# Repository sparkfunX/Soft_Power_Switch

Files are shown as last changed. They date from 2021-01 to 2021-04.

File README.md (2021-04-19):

SparkX Soft Power Switch
===================================================

SparkX Soft Power Switch (SPX-17870) (https://www.sparkfun.com/products/17870)

[*SparkX Soft Power Switch (SPX-17870)*](https://www.sparkfun.com/products/17870)

SparkX Soft Power Switch (SPX-17870) (https://www.sparkfun.com/products/17870)

The Soft Power Switch is a passive, hard on/off switch with software feedback and control. In other words, it's like the on/off switch on a laptop. A simple press will turn the system on. Another press can (with MCU intervention) turn off the system. And if things go really wrong, pressing and holding the button will force a power-down. If you're building something with an enclosed battery and need a good power button, this is the board you need.

The Sense/Control pin can act as an output to a microcontroller indicating the state of the power button (high = not pressed, low = user in pressing power button). This can be used as an input to your firmware to begin to shut down before power is lost. Alternatively, the Sense/Control pin can be driven low by the system forcing power off via software. Additionally, the Fast Off pin can be used to immediately power down a system.

The most common use case is something like this:

* Microcontroller begins running code and checks to see if power button is still being pressed for X milliseconds.
* If not, it's just a tap, go back to sleep.
* If yes, power up and run normal program.

Later...

* User presses power button in normal program
* If power button is pressed for <X milliseconds, it's just a tap, ignore.
* If power button is pressed for >X milliseconds, it's time to power down.

The wake-up and power-down times can be tweaked for your own user experience but we found 500ms for power up and 2s for power down work really well.

If needed, pads are provided for a larger, external button. A measurement jumper is available to measure passive and active current so you can verify the quiescent current of your system.

The Soft Power Switch supports battery charging. If the target device has onboard LiPo charging, current can be passed back through the cut-off circuit and charge the battery.

The Soft Power Switch works up to 12V. There is a 3.3V clamping diode to prevent over-voltage exposure.

The current design is good but has a few problems. The 22uF cap we used requires an override time of 13 seconds. Under normal operation, the system will power down as quickly as you define in the code (1-2s) so users will rarely experience this. But if the system locks up, 13s is a long time to wait. We've also seen a few edge cases (low load or no load) where the override cut-off occurs only after the button is held for >13s and then released. This is caused by shorting between the finger on the button and the near by capacitor. Using an external button allows the unit to power down correctly every time.

We'll continue to refine the design but it's really handy as it is so we decided to release it!

Pros:

* Very low <50nA quiescent current
* Hard override power down in case your microcontroller loses its mind
* Sense/Control pin can be connected to a microcontroller 

Cons:

* Limited to 4A
* No AC loads

Repository Contents
-------------------
* **/Firmware** - Example sketches demonstrating how to read and control the switch
* **/Hardware** - Eagle design files (.brd, .sch)
* **LICENSE.md** - license information

Product Versions
----------------
* [SPX-17870](https://www.sparkfun.com/products/17870) - Original SparkX Release.

License Information
-------------------

This product is _**open source**_!

Please review the LICENSE.md file for license information.

If you have any questions or concerns on licensing, please contact technical support on our [SparkFun forums](https://forum.sparkfun.com/viewforum.php?f=123).

Distributed as-is; no warranty is given.

- Your friends at SparkFun.

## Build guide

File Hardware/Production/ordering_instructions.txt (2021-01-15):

panel size, 143x139mm
PCB thickness, 1.6mm
number of layers, 2
soldermask color, Black
silkscreen color, White
oz copper, 1oz
finish, HASL lead free
stencils, none
pcs per panel, 30
min trace width, 0.3048mm / 0.0120in
min drill size, 0.3048mm / 0.0120in

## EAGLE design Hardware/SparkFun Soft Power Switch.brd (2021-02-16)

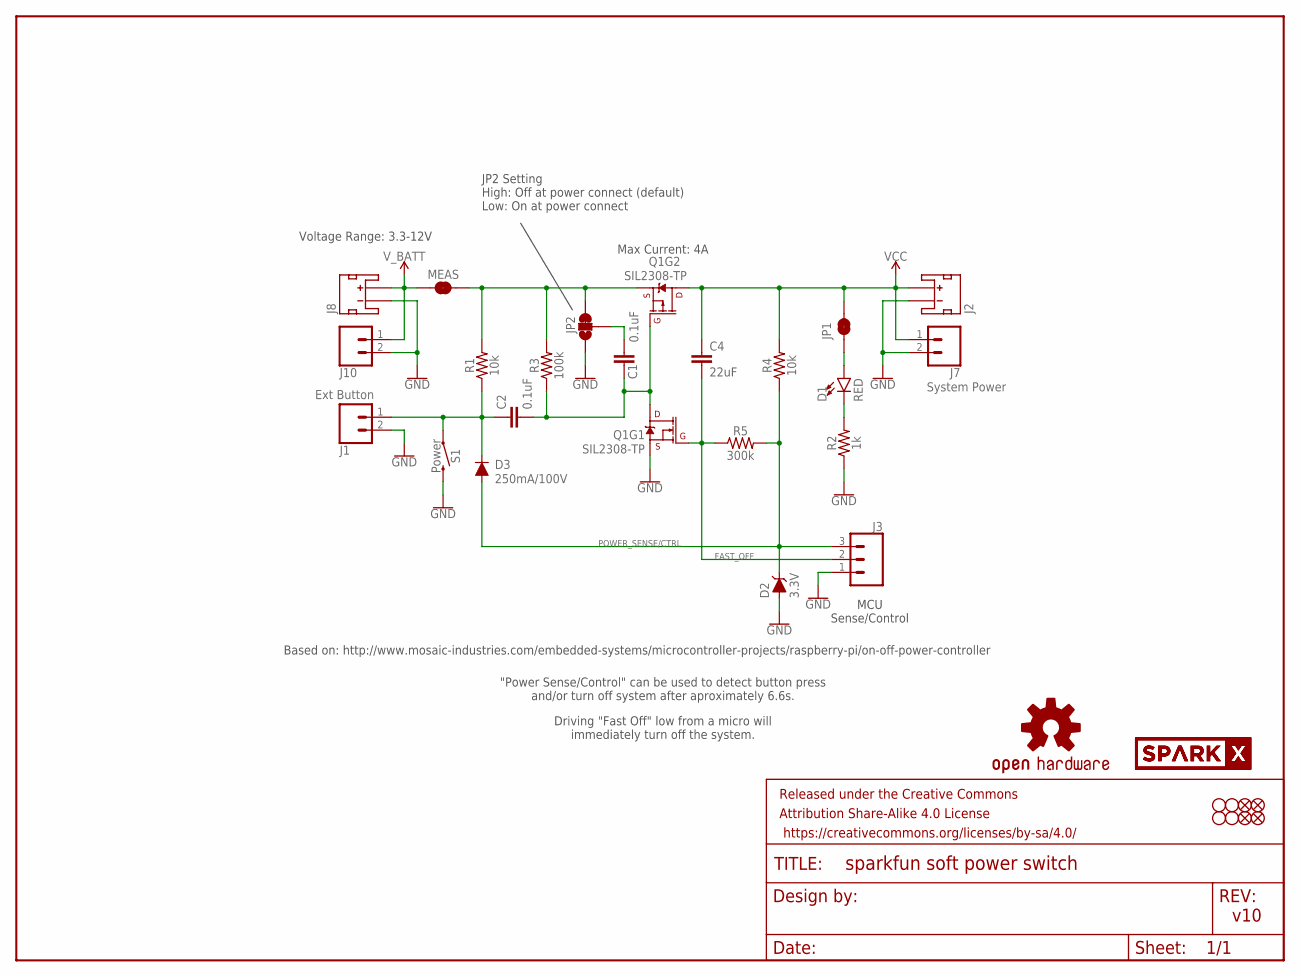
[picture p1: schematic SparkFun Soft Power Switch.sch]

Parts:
C1, C2: 0.1uF; 0603
C4: 22uF; 0805
D1: RED; LED-0603
D2: 3.3V; SOD-323
D3: 250mA/100V; SOD-323
FD1, FD2, FD3, FD4: FIDUCIAL1X2; FIDUCIAL-1X2
FRAME1: FRAME-LETTER; CREATIVE_COMMONS
H1, H2, H3, H4: STAND-OFF
J1: Ext Button; 1X02_NO_SILK
J2, J8: JST_2MM_MALE; JST-2-SMD
J3: CONN_031X03_NO_SILK; 1X03_NO_SILK
J7: System Power; 1X02_NO_SILK
J10: CONN_021X02_NO_SILK; 1X02_NO_SILK
JP1: JUMPER-SMT_2_NC_TRACE_SILK; SMT-JUMPER_2_NC_TRACE_SILK
JP2: JUMPER-SMT_3_1-NC_TRACE_SILK; SMT-JUMPER_3_1-NC_TRACE_SILK
LOGO1: OSHW-LOGOS; OSHW-LOGO-S
MEAS: JUMPER-COMBO_2_NC_TRACE; COMBO-JUMPER_2_NC_TRACE
Q1: SIL2308-TP; SOT26
R1, R4: 10k; 0603
R2: 1k; 0603
R3: 100k; 0603
R5: 300k; 0603
S1: Power; TACTILE_SWITCH_SMD_5.2MM
U$1: SPARKX-LOGO3; SPARKX-SMALL
U$15: SPARKX-LOGO2; SPARKX-TINY

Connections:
FAST_OFF: C4.2, J3.2, Q1.G1 (G), R5.1
GND: D2.A, J1.2, J2.1 (-), J3.1, J7.2, J8.1 (-), J10.2, JP2.1, Q1.S1 (S), R2.1, S1.3 (2)
unnamed: C1.2, JP2.2
unnamed: D1.A, JP1.1
unnamed: D1.C, R2.2
unnamed: C1.1, C2.2, Q1.D1 (D), Q1.G2 (G), R3.1
POWER_BTN: C2.1, D3.C, J1.1, R1.1, S1.1
POWER_SENSE/CTRL: D2.C, D3.A, J3.3, R4.1, R5.2
VCC: C4.1, J2.2 (+), J7.1, JP1.2, Q1.D2 (D), R4.2
V_BATT: J8.2 (+), J10.1, MEAS.1, MEAS.3 (1)
V_IN: JP2.3, MEAS.2, MEAS.4 (2), Q1.S2 (S), R1.2, R3.2

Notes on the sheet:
v10
Voltage Range: 3.3-12V
Based on: http://www.mosaic-industries.com/embedded-systems/microcontroller-projects/raspberry-pi/on-off-power-controller
Max Current: 4A
JP2 Setting High: Off at power connect (default) Low: On at power connect
MCU Sense/Control
"Power Sense/Control" can be used to detect button press and/or turn off system after aproximately 6.6s.
Driving "Fast Off" low from a micro will immediately turn off the system.

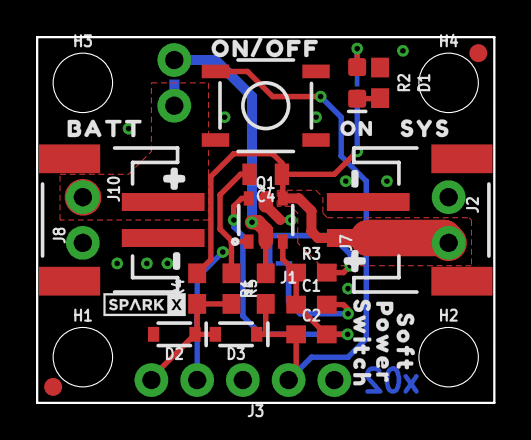
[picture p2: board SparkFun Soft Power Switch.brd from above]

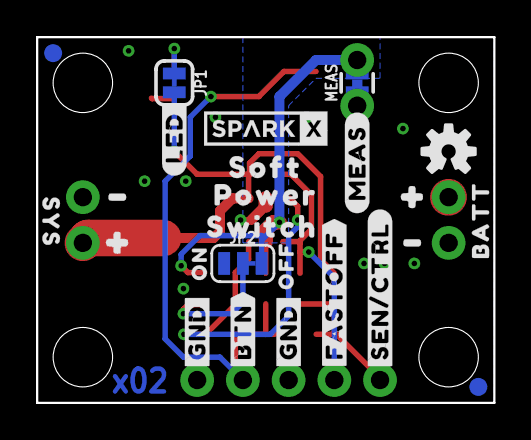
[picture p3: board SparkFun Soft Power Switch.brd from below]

Board: 2 copper layers, 25.4 x 20.3 mm, 63 parts (25 on the bottom side), 11 nets.

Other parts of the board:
U$2: #BTN#2
U$3, U$4: #GND#0
U$5: #SEN#CTRL#1
U$6: ON#OFF0
U$7, U$29: BATT0
U$8, U$31: SYS1
U$9, U$10, U$14, U$22: #0
U$11, U$12, U$20, U$23: #1
U$13: #MEAS#0
U$16: OFF1
U$17: SWITCH2
U$18, U$25: ON0
U$19: #LED#0
U$21: SOFT_0
U$24: POWER_1
U$26: #FASTOFF#0
U$27: SOFT0
U$28: POWER1
U$30: SWITCH_2

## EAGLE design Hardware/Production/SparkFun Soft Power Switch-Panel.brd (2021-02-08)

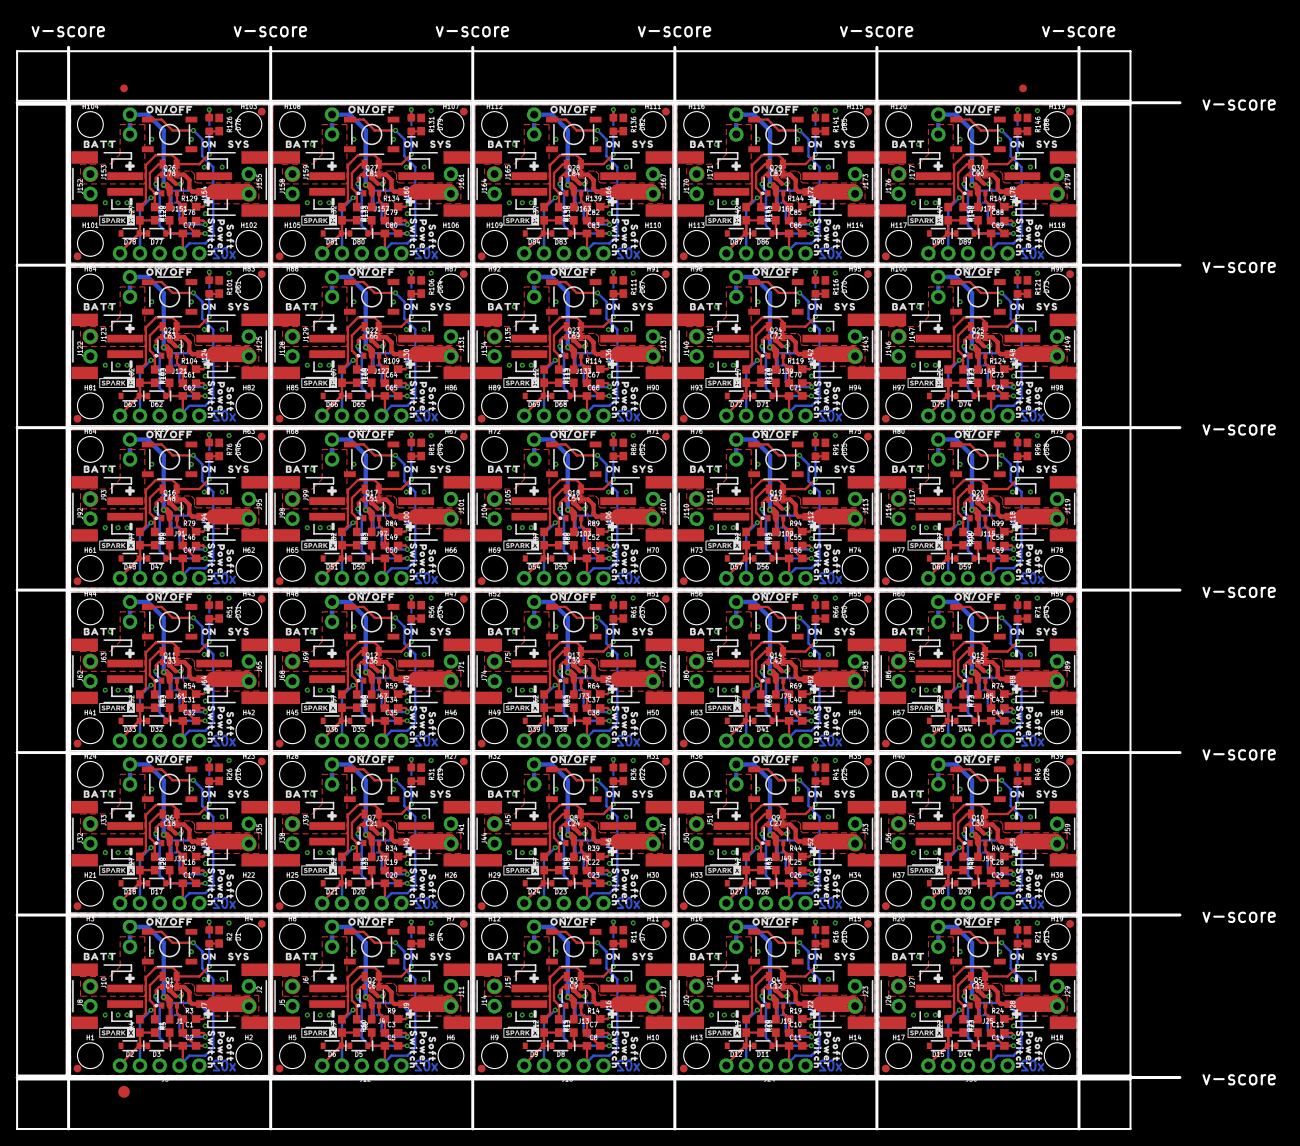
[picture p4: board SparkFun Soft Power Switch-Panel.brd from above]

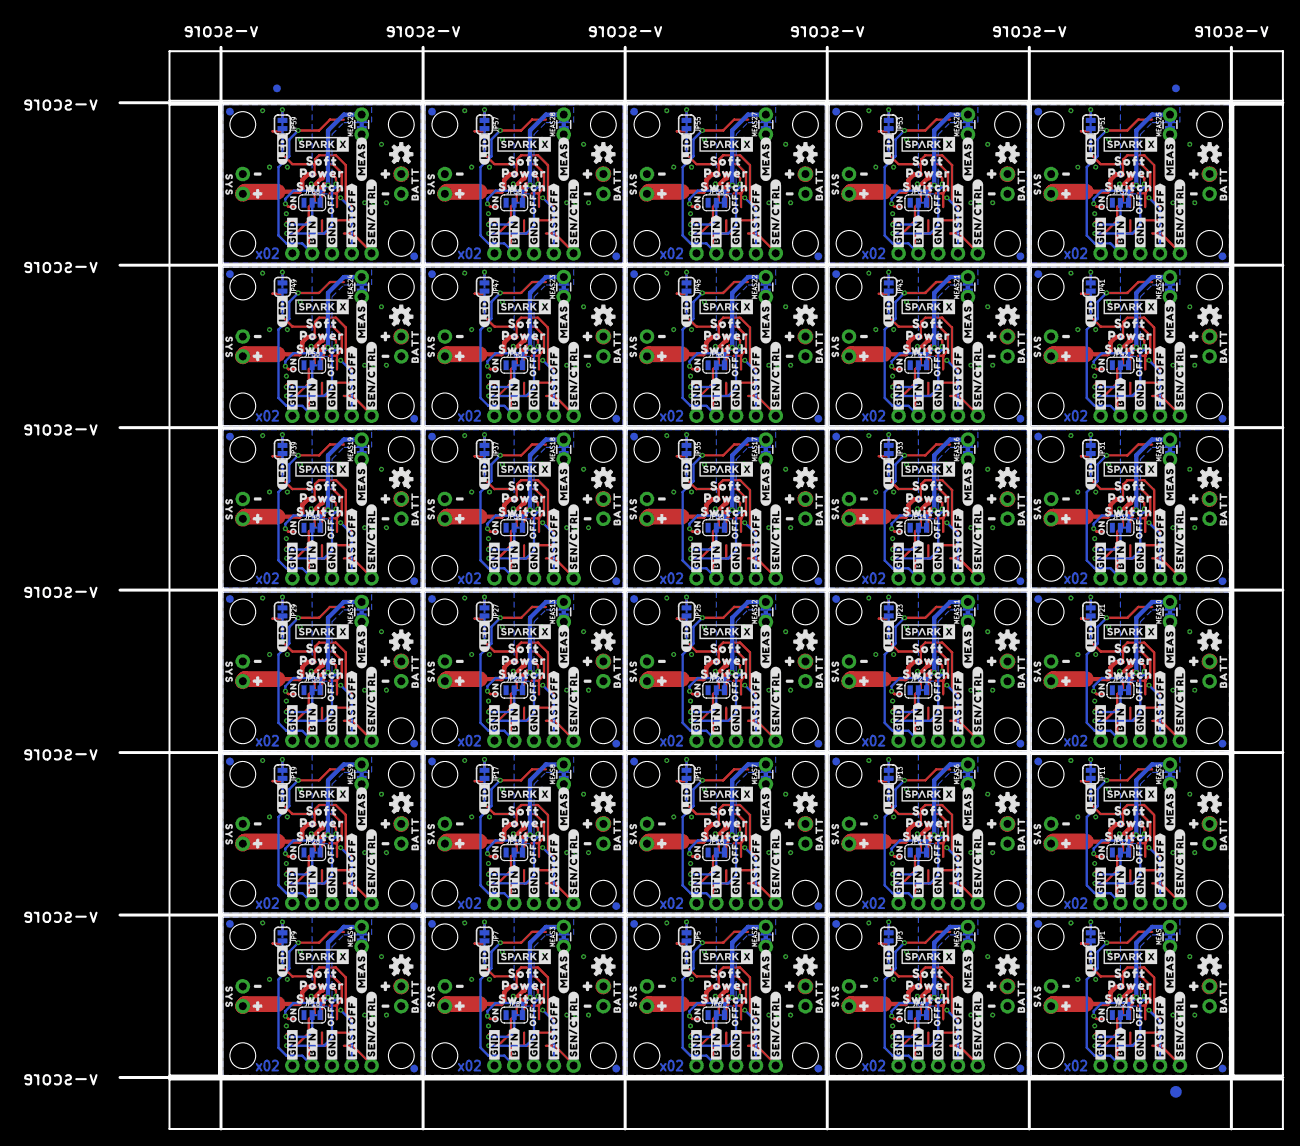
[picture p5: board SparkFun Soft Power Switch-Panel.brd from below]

Board: 2 copper layers, 149.1 x 138.7 mm, 1866 parts (753 on the bottom side), 330 nets.

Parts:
C1, C2, C3, C5, C7, C8, C10, C11, C13, C14, C16, C17, C19, C20, C22, C23, C25, C26, C28, C29, C31, C32, C34, C35, C37, C38, C40, C41, C43, C44, C46, C47, C49, C50, C52, C53, C55, C56, C58, C59, C61, C62, C64, C65, C67, C68, C70, C71, C73, C74, C76, C77, C79, C80, C82, C83, C85, C86, C88, C89: 0.1uF; 0603
C4, C6, C9, C12, C15, C18, C21, C24, C27, C30, C33, C36, C39, C42, C45, C48, C51, C54, C57, C60, C63, C66, C69, C72, C75, C78, C81, C84, C87, C90: 22uF; 0805
D1, D4, D7, D10, D13, D16, D19, D22, D25, D28, D31, D34, D37, D40, D43, D46, D49, D52, D55, D58, D61, D64, D67, D70, D73, D76, D79, D82, D85, D88: Power; LED-0603
D2, D6, D9, D12, D15, D18, D21, D24, D27, D30, D33, D36, D39, D42, D45, D48, D51, D54, D57, D60, D63, D66, D69, D72, D75, D78, D81, D84, D87, D90: 3.3V; SOD-323
D3, D5, D8, D11, D14, D17, D20, D23, D26, D29, D32, D35, D38, D41, D44, D47, D50, D53, D56, D59, D62, D65, D68, D71, D74, D77, D80, D83, D86, D89: 250mA/100V; SOD-323
E$1, E$2, E$3, E$4: FIDUCIAL-1X2
E$5, E$6: FIDUCIAL-1.5X3
FD1, FD2, FD3, FD4, FD5, FD6, FD7, FD8, FD9, FD10, FD11, FD12, FD13, FD14, FD15, FD16, FD17, FD18, FD19, FD20, FD21, FD22, FD23, FD24, FD25, FD26, FD27, FD28, FD29, FD30, FD31, FD32, FD33, FD34, FD35, FD36, FD37, FD38, FD39, FD40, FD41, FD42, FD43, FD44, FD45, FD46, FD47, FD48, FD49, FD50, FD51, FD52, FD53, FD54, FD55, FD56, FD57, FD58, FD59, FD60, FD61, FD62, FD63, FD64, FD65, FD66, FD67, FD68, FD69, FD70, FD71, FD72, FD73, FD74, FD75, FD76, FD77, FD78, FD79, FD80, FD81, FD82, FD83, FD84, FD85, FD86, FD87, FD88, FD89, FD90, FD91, FD92, FD93, FD94, FD95, FD96, FD97, FD98, FD99, FD100, FD101, FD102, FD103, FD104, FD105, FD106, FD107, FD108, FD109, FD110, FD111, FD112, FD113, FD114, FD115, FD116, FD117, FD118, FD119, FD120: FIDUCIAL1X2; FIDUCIAL-1X2
H1, H2, H3, H4, H5, H6, H7, H8, H9, H10, H11, H12, H13, H14, H15, H16, H17, H18, H19, H20, H21, H22, H23, H24, H25, H26, H27, H28, H29, H30, H31, H32, H33, H34, H35, H36, H37, H38, H39, H40, H41, H42, H43, H44, H45, H46, H47, H48, H49, H50, H51, H52, H53, H54, H55, H56, H57, H58, H59, H60, H61, H62, H63, H64, H65, H66, H67, H68, H69, H70, H71, H72, H73, H74, H75, H76, H77, H78, H79, H80, H81, H82, H83, H84, H85, H86, H87, H88, H89, H90, H91, H92, H93, H94, H95, H96, H97, H98, H99, H100, H101, H102, H103, H104, H105, H106, H107, H108, H109, H110, H111, H112, H113, H114, H115, H116, H117, H118, H119, H120: STAND-OFF
J1, J4, J13, J19, J25, J31, J37, J43, J49, J55, J61, J67, J73, J79, J85, J91, J97, J103, J109, J115, J121, J127, J133, J139, J145, J151, J157, J163, J169, J175: Ext Button; 1X02_NO_SILK
J2, J5, J8, J11, J14, J17, J20, J23, J26, J29, J32, J35, J38, J41, J44, J47, J50, J53, J56, J59, J62, J65, J68, J71, J74, J77, J80, J83, J86, J89, J92, J95, J98, J101, J104, J107, J110, J113, J116, J119, J122, J125, J128, J131, J134, J137, J140, J143, J146, J149, J152, J155, J158, J161, J164, J167, J170, J173, J176, J179: JST-2-SMD
J3, J12, J18, J24, J30, J36, J42, J48, J54, J60, J66, J72, J78, J84, J90, J96, J102, J108, J114, J120, J126, J132, J138, J144, J150, J156, J162, J168, J174, J180: 1X03_NO_SILK
J6, J10, J15, J21, J27, J33, J39, J45, J51, J57, J63, J69, J75, J81, J87, J93, J99, J105, J111, J117, J123, J129, J135, J141, J147, J153, J159, J165, J171, J177: 1X02_NO_SILK
J7, J9, J16, J22, J28, J34, J40, J46, J52, J58, J64, J70, J76, J82, J88, J94, J100, J106, J112, J118, J124, J130, J136, J142, J148, J154, J160, J166, J172, J178: System Power; 1X02_NO_SILK
JP1, JP3, JP5, JP7, JP9, JP11, JP13, JP15, JP17, JP19, JP21, JP23, JP25, JP27, JP29, JP31, JP33, JP35, JP37, JP39, JP41, JP43, JP45, JP47, JP49, JP51, JP53, JP55, JP57, JP59: SMT-JUMPER_2_NC_TRACE_SILK
JP2, JP4, JP6, JP8, JP10, JP12, JP14, JP16, JP18, JP20, JP22, JP24, JP26, JP28, JP30, JP32, JP34, JP36, JP38, JP40, JP42, JP44, JP46, JP48, JP50, JP52, JP54, JP56, JP58, JP60: SMT-JUMPER_3_1-NC_TRACE_SILK
LOGO1, LOGO2, LOGO3, LOGO4, LOGO5, LOGO6, LOGO7, LOGO8, LOGO9, LOGO10, LOGO11, LOGO12, LOGO13, LOGO14, LOGO15, LOGO16, LOGO17, LOGO18, LOGO19, LOGO20, LOGO21, LOGO22, LOGO23, LOGO24, LOGO25, LOGO26, LOGO27, LOGO28, LOGO29, LOGO30: OSHW-LOGOS; OSHW-LOGO-S
MEAS, MEAS1, MEAS2, MEAS3, MEAS4, MEAS5, MEAS6, MEAS7, MEAS8, MEAS9, MEAS10, MEAS11, MEAS12, MEAS13, MEAS14, MEAS15, MEAS16, MEAS17, MEAS18, MEAS19, MEAS20, MEAS21, MEAS22, MEAS23, MEAS24, MEAS25, MEAS26, MEAS27, MEAS28, MEAS29: COMBO-JUMPER_2_NC_TRACE
Q1, Q2, Q3, Q4, Q5, Q6, Q7, Q8, Q9, Q10, Q11, Q12, Q13, Q14, Q15, Q16, Q17, Q18, Q19, Q20, Q21, Q22, Q23, Q24, Q25, Q26, Q27, Q28, Q29, Q30: SIL2308-TP; SOT26
R1, R4, R7, R10, R12, R15, R17, R20, R22, R25, R27, R30, R32, R35, R37, R40, R42, R45, R47, R50, R52, R55, R57, R60, R62, R65, R67, R70, R72, R75, R77, R80, R82, R85, R87, R90, R92, R95, R97, R100, R102, R105, R107, R110, R112, R115, R117, R120, R122, R125, R127, R130, R132, R135, R137, R140, R142, R145, R147, R150: 10k; 0603
R2, R6, R11, R16, R21, R26, R31, R36, R41, R46, R51, R56, R61, R66, R71, R76, R81, R86, R91, R96, R101, R106, R111, R116, R121, R126, R131, R136, R141, R146: 1k; 0603
R3, R9, R14, R19, R24, R29, R34, R39, R44, R49, R54, R59, R64, R69, R74, R79, R84, R89, R94, R99, R104, R109, R114, R119, R124, R129, R134, R139, R144, R149: 100k; 0603
R5, R8, R13, R18, R23, R28, R33, R38, R43, R48, R53, R58, R63, R68, R73, R78, R83, R88, R93, R98, R103, R108, R113, R118, R123, R128, R133, R138, R143, R148: 300k; 0603
S1, S2, S3, S4, S5, S6, S7, S8, S9, S10, S11, S12, S13, S14, S15, S16, S17, S18, S19, S20, S21, S22, S23, S24, S25, S26, S27, S28, S29, S30: Power; TACTILE_SWITCH_SMD_5.2MM
U$1, U$32, U$63, U$94, U$125, U$156, U$187, U$218, U$249, U$280, U$311, U$342, U$373, U$404, U$435, U$466, U$497, U$528, U$559, U$590, U$621, U$652, U$683, U$714, U$745, U$776, U$807, U$838, U$869, U$900: SPARKX-LOGO3; SPARKX-SMALL
U$2, U$33, U$64, U$95, U$126, U$157, U$188, U$219, U$250, U$281, U$312, U$343, U$374, U$405, U$436, U$467, U$498, U$529, U$560, U$591, U$622, U$653, U$684, U$715, U$746, U$777, U$808, U$839, U$870, U$901: #BTN#2
U$3, U$4, U$34, U$35, U$65, U$66, U$96, U$97, U$127, U$128, U$158, U$159, U$189, U$190, U$220, U$221, U$251, U$252, U$282, U$283, U$313, U$314, U$344, U$345, U$375, U$376, U$406, U$407, U$437, U$438, U$468, U$469, U$499, U$500, U$530, U$531, U$561, U$562, U$592, U$593, U$623, U$624, U$654, U$655, U$685, U$686, U$716, U$717, U$747, U$748, U$778, U$779, U$809, U$810, U$840, U$841, U$871, U$872, U$902, U$903: #GND#0
U$5, U$36, U$67, U$98, U$129, U$160, U$191, U$222, U$253, U$284, U$315, U$346, U$377, U$408, U$439, U$470, U$501, U$532, U$563, U$594, U$625, U$656, U$687, U$718, U$749, U$780, U$811, U$842, U$873, U$904: #SEN#CTRL#1
U$6, U$37, U$68, U$99, U$130, U$161, U$192, U$223, U$254, U$285, U$316, U$347, U$378, U$409, U$440, U$471, U$502, U$533, U$564, U$595, U$626, U$657, U$688, U$719, U$750, U$781, U$812, U$843, U$874, U$905: ON#OFF0
U$7, U$29, U$38, U$60, U$69, U$91, U$100, U$122, U$131, U$153, U$162, U$184, U$193, U$215, U$224, U$246, U$255, U$277, U$286, U$308, U$317, U$339, U$348, U$370, U$379, U$401, U$410, U$432, U$441, U$463, U$472, U$494, U$503, U$525, U$534, U$556, U$565, U$587, U$596, U$618, U$627, U$649, U$658, U$680, U$689, U$711, U$720, U$742, U$751, U$773, U$782, U$804, U$813, U$835, U$844, U$866, U$875, U$897, U$906, U$928: BATT0
U$8, U$31, U$39, U$61, U$70, U$92, U$101, U$123, U$132, U$154, U$163, U$185, U$194, U$216, U$225, U$247, U$256, U$278, U$287, U$309, U$318, U$340, U$349, U$371, U$380, U$402, U$411, U$433, U$442, U$464, U$473, U$495, U$504, U$526, U$535, U$557, U$566, U$588, U$597, U$619, U$628, U$650, U$659, U$681, U$690, U$712, U$721, U$743, U$752, U$774, U$783, U$805, U$814, U$836, U$845, U$867, U$876, U$898, U$907, U$929: SYS1
U$9, U$10, U$14, U$22, U$40, U$41, U$48, U$50, U$71, U$72, U$79, U$81, U$102, U$103, U$110, U$112, U$133, U$134, U$141, U$143, U$164, U$165, U$172, U$174, U$195, U$196, U$203, U$205, U$226, U$227, U$234, U$236, U$257, U$258, U$265, U$267, U$288, U$289, U$296, U$298, U$319, U$320, U$327, U$329, U$350, U$351, U$358, U$360, U$381, U$382, U$389, U$391, U$412, U$413, U$420, U$422, U$443, U$444, U$451, U$453, U$474, U$475, U$482, U$484, U$505, U$506, U$513, U$515, U$536, U$537, U$544, U$546, U$567, U$568, U$575, U$577, U$598, U$599, U$606, U$608, U$629, U$630, U$637, U$639, U$660, U$661, U$668, U$670, U$691, U$692, U$699, U$701, U$722, U$723, U$730, U$732, U$753, U$754, U$761, U$763, U$784, U$785, U$792, U$794, U$815, U$816, U$823, U$825, U$846, U$847, U$854, U$856, U$877, U$878, U$885, U$887, U$908, U$909, U$916, U$918: #0
U$11, U$12, U$20, U$23, U$42, U$43, U$49, U$51, U$73, U$74, U$80, U$82, U$104, U$105, U$111, U$113, U$135, U$136, U$142, U$144, U$166, U$167, U$173, U$175, U$197, U$198, U$204, U$206, U$228, U$229, U$235, U$237, U$259, U$260, U$266, U$268, U$290, U$291, U$297, U$299, U$321, U$322, U$328, U$330, U$352, U$353, U$359, U$361, U$383, U$384, U$390, U$392, U$414, U$415, U$421, U$423, U$445, U$446, U$452, U$454, U$476, U$477, U$483, U$485, U$507, U$508, U$514, U$516, U$538, U$539, U$545, U$547, U$569, U$570, U$576, U$578, U$600, U$601, U$607, U$609, U$631, U$632, U$638, U$640, U$662, U$663, U$669, U$671, U$693, U$694, U$700, U$702, U$724, U$725, U$731, U$733, U$755, U$756, U$762, U$764, U$786, U$787, U$793, U$795, U$817, U$818, U$824, U$826, U$848, U$849, U$855, U$857, U$879, U$880, U$886, U$888, U$910, U$911, U$917, U$919: #1
U$13, U$44, U$75, U$106, U$137, U$168, U$199, U$230, U$261, U$292, U$323, U$354, U$385, U$416, U$447, U$478, U$509, U$540, U$571, U$602, U$633, U$664, U$695, U$726, U$757, U$788, U$819, U$850, U$881, U$912: #MEAS#0
U$15, U$62, U$93, U$124, U$155, U$186, U$217, U$248, U$279, U$310, U$341, U$372, U$403, U$434, U$465, U$496, U$527, U$558, U$589, U$620, U$651, U$682, U$713, U$744, U$775, U$806, U$837, U$868, U$899, U$930: SPARKX-LOGO2; SPARKX-TINY
U$16, U$57, U$88, U$119, U$150, U$181, U$212, U$243, U$274, U$305, U$336, U$367, U$398, U$429, U$460, U$491, U$522, U$553, U$584, U$615, U$646, U$677, U$708, U$739, U$770, U$801, U$832, U$863, U$894, U$925: OFF1
U$17, U$45, U$76, U$107, U$138, U$169, U$200, U$231, U$262, U$293, U$324, U$355, U$386, U$417, U$448, U$479, U$510, U$541, U$572, U$603, U$634, U$665, U$696, U$727, U$758, U$789, U$820, U$851, U$882, U$913: SWITCH2
U$18, U$25, U$46, U$58, U$77, U$89, U$108, U$120, U$139, U$151, U$170, U$182, U$201, U$213, U$232, U$244, U$263, U$275, U$294, U$306, U$325, U$337, U$356, U$368, U$387, U$399, U$418, U$430, U$449, U$461, U$480, U$492, U$511, U$523, U$542, U$554, U$573, U$585, U$604, U$616, U$635, U$647, U$666, U$678, U$697, U$709, U$728, U$740, U$759, U$771, U$790, U$802, U$821, U$833, U$852, U$864, U$883, U$895, U$914, U$926: ON0
U$19, U$47, U$78, U$109, U$140, U$171, U$202, U$233, U$264, U$295, U$326, U$357, U$388, U$419, U$450, U$481, U$512, U$543, U$574, U$605, U$636, U$667, U$698, U$729, U$760, U$791, U$822, U$853, U$884, U$915: #LED#0
U$21, U$55, U$86, U$117, U$148, U$179, U$210, U$241, U$272, U$303, U$334, U$365, U$396, U$427, U$458, U$489, U$520, U$551, U$582, U$613, U$644, U$675, U$706, U$737, U$768, U$799, U$830, U$861, U$892, U$923: SOFT_0
U$24, U$56, U$87, U$118, U$149, U$180, U$211, U$242, U$273, U$304, U$335, U$366, U$397, U$428, U$459, U$490, U$521, U$552, U$583, U$614, U$645, U$676, U$707, U$738, U$769, U$800, U$831, U$862, U$893, U$924: POWER_1
U$26, U$59, U$90, U$121, U$152, U$183, U$214, U$245, U$276, U$307, U$338, U$369, U$400, U$431, U$462, U$493, U$524, U$555, U$586, U$617, U$648, U$679, U$710, U$741, U$772, U$803, U$834, U$865, U$896, U$927: #FASTOFF#0
U$27, U$52, U$83, U$114, U$145, U$176, U$207, U$238, U$269, U$300, U$331, U$362, U$393, U$424, U$455, U$486, U$517, U$548, U$579, U$610, U$641, U$672, U$703, U$734, U$765, U$796, U$827, U$858, U$889, U$920: SOFT0
U$28, U$53, U$84, U$115, U$146, U$177, U$208, U$239, U$270, U$301, U$332, U$363, U$394, U$425, U$456, U$487, U$518, U$549, U$580, U$611, U$642, U$673, U$704, U$735, U$766, U$797, U$828, U$859, U$890, U$921: POWER1
U$30, U$54, U$85, U$116, U$147, U$178, U$209, U$240, U$271, U$302, U$333, U$364, U$395, U$426, U$457, U$488, U$519, U$550, U$581, U$612, U$643, U$674, U$705, U$736, U$767, U$798, U$829, U$860, U$891, U$922: SWITCH_2

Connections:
FAST_OFF: C4.2, J3.2, Q1.G1, R5.1
FAST_OFF1: C6.2, J12.2, Q2.G1, R8.1
FAST_OFF2: C9.2, J18.2, Q3.G1, R13.1
FAST_OFF3: C12.2, J24.2, Q4.G1, R18.1
FAST_OFF4: C15.2, J30.2, Q5.G1, R23.1
FAST_OFF5: C18.2, J36.2, Q6.G1, R28.1
FAST_OFF6: C21.2, J42.2, Q7.G1, R33.1
FAST_OFF7: C24.2, J48.2, Q8.G1, R38.1
FAST_OFF8: C27.2, J54.2, Q9.G1, R43.1
FAST_OFF9: C30.2, J60.2, Q10.G1, R48.1
FAST_OFF10: C33.2, J66.2, Q11.G1, R53.1
FAST_OFF11: C36.2, J72.2, Q12.G1, R58.1
FAST_OFF12: C39.2, J78.2, Q13.G1, R63.1
FAST_OFF13: C42.2, J84.2, Q14.G1, R68.1
FAST_OFF14: C45.2, J90.2, Q15.G1, R73.1
FAST_OFF15: C48.2, J96.2, Q16.G1, R78.1
FAST_OFF16: C51.2, J102.2, Q17.G1, R83.1
FAST_OFF17: C54.2, J108.2, Q18.G1, R88.1
FAST_OFF18: C57.2, J114.2, Q19.G1, R93.1
FAST_OFF19: C60.2, J120.2, Q20.G1, R98.1
FAST_OFF20: C63.2, J126.2, Q21.G1, R103.1
FAST_OFF21: C66.2, J132.2, Q22.G1, R108.1
FAST_OFF22: C69.2, J138.2, Q23.G1, R113.1
FAST_OFF23: C72.2, J144.2, Q24.G1, R118.1
FAST_OFF24: C75.2, J150.2, Q25.G1, R123.1
FAST_OFF25: C78.2, J156.2, Q26.G1, R128.1
FAST_OFF26: C81.2, J162.2, Q27.G1, R133.1
FAST_OFF27: C84.2, J168.2, Q28.G1, R138.1
FAST_OFF28: C87.2, J174.2, Q29.G1, R143.1
FAST_OFF29: C90.2, J180.2, Q30.G1, R148.1
GND: D2.A, J1.2, J2.1, J3.1, J7.2, J8.1, J10.2, JP2.1, Q1.S1, R2.1, S1.3
GND1: D6.A, J4.2, J5.1, J6.2, J9.2, J11.1, J12.1, JP4.1, Q2.S1, R6.1, S2.3
GND2: D9.A, J13.2, J14.1, J15.2, J16.2, J17.1, J18.1, JP6.1, Q3.S1, R11.1, S3.3
GND3: D12.A, J19.2, J20.1, J21.2, J22.2, J23.1, J24.1, JP8.1, Q4.S1, R16.1, S4.3
GND4: D15.A, J25.2, J26.1, J27.2, J28.2, J29.1, J30.1, JP10.1, Q5.S1, R21.1, S5.3
GND5: D18.A, J31.2, J32.1, J33.2, J34.2, J35.1, J36.1, JP12.1, Q6.S1, R26.1, S6.3
GND6: D21.A, J37.2, J38.1, J39.2, J40.2, J41.1, J42.1, JP14.1, Q7.S1, R31.1, S7.3
GND7: D24.A, J43.2, J44.1, J45.2, J46.2, J47.1, J48.1, JP16.1, Q8.S1, R36.1, S8.3
GND8: D27.A, J49.2, J50.1, J51.2, J52.2, J53.1, J54.1, JP18.1, Q9.S1, R41.1, S9.3
GND9: D30.A, J55.2, J56.1, J57.2, J58.2, J59.1, J60.1, JP20.1, Q10.S1, R46.1, S10.3
GND10: D33.A, J61.2, J62.1, J63.2, J64.2, J65.1, J66.1, JP22.1, Q11.S1, R51.1, S11.3
GND11: D36.A, J67.2, J68.1, J69.2, J70.2, J71.1, J72.1, JP24.1, Q12.S1, R56.1, S12.3
GND12: D39.A, J73.2, J74.1, J75.2, J76.2, J77.1, J78.1, JP26.1, Q13.S1, R61.1, S13.3
GND13: D42.A, J79.2, J80.1, J81.2, J82.2, J83.1, J84.1, JP28.1, Q14.S1, R66.1, S14.3
GND14: D45.A, J85.2, J86.1, J87.2, J88.2, J89.1, J90.1, JP30.1, Q15.S1, R71.1, S15.3
GND15: D48.A, J91.2, J92.1, J93.2, J94.2, J95.1, J96.1, JP32.1, Q16.S1, R76.1, S16.3
GND16: D51.A, J97.2, J98.1, J99.2, J100.2, J101.1, J102.1, JP34.1, Q17.S1, R81.1, S17.3
GND17: D54.A, J103.2, J104.1, J105.2, J106.2, J107.1, J108.1, JP36.1, Q18.S1, R86.1, S18.3
GND18: D57.A, J109.2, J110.1, J111.2, J112.2, J113.1, J114.1, JP38.1, Q19.S1, R91.1, S19.3
GND19: D60.A, J115.2, J116.1, J117.2, J118.2, J119.1, J120.1, JP40.1, Q20.S1, R96.1, S20.3
GND20: D63.A, J121.2, J122.1, J123.2, J124.2, J125.1, J126.1, JP42.1, Q21.S1, R101.1, S21.3
GND21: D66.A, J127.2, J128.1, J129.2, J130.2, J131.1, J132.1, JP44.1, Q22.S1, R106.1, S22.3
GND22: D69.A, J133.2, J134.1, J135.2, J136.2, J137.1, J138.1, JP46.1, Q23.S1, R111.1, S23.3
GND23: D72.A, J139.2, J140.1, J141.2, J142.2, J143.1, J144.1, JP48.1, Q24.S1, R116.1, S24.3
GND24: D75.A, J145.2, J146.1, J147.2, J148.2, J149.1, J150.1, JP50.1, Q25.S1, R121.1, S25.3
GND25: D78.A, J151.2, J152.1, J153.2, J154.2, J155.1, J156.1, JP52.1, Q26.S1, R126.1, S26.3
GND26: D81.A, J157.2, J158.1, J159.2, J160.2, J161.1, J162.1, JP54.1, Q27.S1, R131.1, S27.3
GND27: D84.A, J163.2, J164.1, J165.2, J166.2, J167.1, J168.1, JP56.1, Q28.S1, R136.1, S28.3
GND28: D87.A, J169.2, J170.1, J171.2, J172.2, J173.1, J174.1, JP58.1, Q29.S1, R141.1, S29.3
GND29: D90.A, J175.2, J176.1, J177.2, J178.2, J179.1, J180.1, JP60.1, Q30.S1, R146.1, S30.3
unnamed: C1.2, JP2.2
unnamed: D1.A, JP1.1
unnamed: D4.C, R6.2
unnamed: C3.1, C5.2, Q2.D1, Q2.G2, R9.1
unnamed: D4.A, JP3.1
unnamed: D1.C, R2.2
unnamed: C3.2, JP4.2
unnamed: D7.C, R11.2
unnamed: C7.1, C8.2, Q3.D1, Q3.G2, R14.1
unnamed: D7.A, JP5.1
unnamed: C7.2, JP6.2
unnamed: D10.C, R16.2
unnamed: C10.1, C11.2, Q4.D1, Q4.G2, R19.1
unnamed: D10.A, JP7.1
unnamed: C1.1, C2.2, Q1.D1, Q1.G2, R3.1
unnamed: C10.2, JP8.2
unnamed: D13.C, R21.2
unnamed: C13.1, C14.2, Q5.D1, Q5.G2, R24.1
unnamed: D13.A, JP9.1
unnamed: C13.2, JP10.2
unnamed: D16.C, R26.2
unnamed: C16.1, C17.2, Q6.D1, Q6.G2, R29.1
unnamed: D16.A, JP11.1
unnamed: C16.2, JP12.2
unnamed: D19.C, R31.2
unnamed: C19.1, C20.2, Q7.D1, Q7.G2, R34.1
unnamed: D19.A, JP13.1
unnamed: C19.2, JP14.2
unnamed: D22.C, R36.2
unnamed: C22.1, C23.2, Q8.D1, Q8.G2, R39.1
unnamed: D22.A, JP15.1
unnamed: C22.2, JP16.2
unnamed: D25.C, R41.2
unnamed: C25.1, C26.2, Q9.D1, Q9.G2, R44.1
unnamed: D25.A, JP17.1
unnamed: C25.2, JP18.2
unnamed: D28.C, R46.2
unnamed: C28.1, C29.2, Q10.D1, Q10.G2, R49.1
unnamed: D28.A, JP19.1
unnamed: C28.2, JP20.2
unnamed: D31.C, R51.2
unnamed: C31.1, C32.2, Q11.D1, Q11.G2, R54.1
unnamed: D31.A, JP21.1
unnamed: C31.2, JP22.2
unnamed: D34.C, R56.2
unnamed: C34.1, C35.2, Q12.D1, Q12.G2, R59.1
unnamed: D34.A, JP23.1
unnamed: C34.2, JP24.2
unnamed: D37.C, R61.2
unnamed: C37.1, C38.2, Q13.D1, Q13.G2, R64.1
unnamed: D37.A, JP25.1
unnamed: C37.2, JP26.2
unnamed: D40.C, R66.2
unnamed: C40.1, C41.2, Q14.D1, Q14.G2, R69.1
unnamed: D40.A, JP27.1
unnamed: C40.2, JP28.2
unnamed: D43.C, R71.2
unnamed: C43.1, C44.2, Q15.D1, Q15.G2, R74.1
unnamed: D43.A, JP29.1
unnamed: C43.2, JP30.2
unnamed: D46.C, R76.2
unnamed: C46.1, C47.2, Q16.D1, Q16.G2, R79.1
unnamed: D46.A, JP31.1
unnamed: C46.2, JP32.2
unnamed: D49.C, R81.2
unnamed: C49.1, C50.2, Q17.D1, Q17.G2, R84.1
unnamed: D49.A, JP33.1
unnamed: C49.2, JP34.2
unnamed: D52.C, R86.2
unnamed: C52.1, C53.2, Q18.D1, Q18.G2, R89.1
unnamed: D52.A, JP35.1
unnamed: C52.2, JP36.2
unnamed: D55.C, R91.2
unnamed: C55.1, C56.2, Q19.D1, Q19.G2, R94.1
unnamed: D55.A, JP37.1
unnamed: C55.2, JP38.2
unnamed: D58.C, R96.2
unnamed: C58.1, C59.2, Q20.D1, Q20.G2, R99.1
unnamed: D58.A, JP39.1
unnamed: C58.2, JP40.2
unnamed: D61.C, R101.2
unnamed: C61.1, C62.2, Q21.D1, Q21.G2, R104.1
unnamed: D61.A, JP41.1
unnamed: C61.2, JP42.2
unnamed: D64.C, R106.2
unnamed: C64.1, C65.2, Q22.D1, Q22.G2, R109.1
unnamed: D64.A, JP43.1
unnamed: C64.2, JP44.2
unnamed: D67.C, R111.2
unnamed: C67.1, C68.2, Q23.D1, Q23.G2, R114.1
unnamed: D67.A, JP45.1
unnamed: C67.2, JP46.2
unnamed: D70.C, R116.2
unnamed: C70.1, C71.2, Q24.D1, Q24.G2, R119.1
unnamed: D70.A, JP47.1
unnamed: C70.2, JP48.2
unnamed: D73.C, R121.2
unnamed: C73.1, C74.2, Q25.D1, Q25.G2, R124.1
unnamed: D73.A, JP49.1
unnamed: C73.2, JP50.2
unnamed: D76.C, R126.2
unnamed: C76.1, C77.2, Q26.D1, Q26.G2, R129.1
unnamed: D76.A, JP51.1
unnamed: C76.2, JP52.2
unnamed: D79.C, R131.2
unnamed: C79.1, C80.2, Q27.D1, Q27.G2, R134.1
unnamed: D79.A, JP53.1
unnamed: C79.2, JP54.2
unnamed: D82.C, R136.2
unnamed: C82.1, C83.2, Q28.D1, Q28.G2, R139.1
unnamed: D82.A, JP55.1
unnamed: C82.2, JP56.2
unnamed: D85.C, R141.2
unnamed: C85.1, C86.2, Q29.D1, Q29.G2, R144.1
unnamed: D85.A, JP57.1
unnamed: C85.2, JP58.2
unnamed: D88.C, R146.2
unnamed: C88.1, C89.2, Q30.D1, Q30.G2, R149.1
unnamed: D88.A, JP59.1
unnamed: C88.2, JP60.2
POWER_BTN: C2.1, D3.C, J1.1, R1.1, S1.1
POWER_BTN1: C5.1, D5.C, J4.1, R10.1, S2.1
POWER_BTN2: C8.1, D8.C, J13.1, R15.1, S3.1
POWER_BTN3: C11.1, D11.C, J19.1, R20.1, S4.1
POWER_BTN4: C14.1, D14.C, J25.1, R25.1, S5.1
POWER_BTN5: C17.1, D17.C, J31.1, R30.1, S6.1
POWER_BTN6: C20.1, D20.C, J37.1, R35.1, S7.1
POWER_BTN7: C23.1, D23.C, J43.1, R40.1, S8.1
POWER_BTN8: C26.1, D26.C, J49.1, R45.1, S9.1
POWER_BTN9: C29.1, D29.C, J55.1, R50.1, S10.1
POWER_BTN10: C32.1, D32.C, J61.1, R55.1, S11.1
POWER_BTN11: C35.1, D35.C, J67.1, R60.1, S12.1
POWER_BTN12: C38.1, D38.C, J73.1, R65.1, S13.1
POWER_BTN13: C41.1, D41.C, J79.1, R70.1, S14.1
POWER_BTN14: C44.1, D44.C, J85.1, R75.1, S15.1
POWER_BTN15: C47.1, D47.C, J91.1, R80.1, S16.1
POWER_BTN16: C50.1, D50.C, J97.1, R85.1, S17.1
POWER_BTN17: C53.1, D53.C, J103.1, R90.1, S18.1
POWER_BTN18: C56.1, D56.C, J109.1, R95.1, S19.1
POWER_BTN19: C59.1, D59.C, J115.1, R100.1, S20.1
POWER_BTN20: C62.1, D62.C, J121.1, R105.1, S21.1
POWER_BTN21: C65.1, D65.C, J127.1, R110.1, S22.1
POWER_BTN22: C68.1, D68.C, J133.1, R115.1, S23.1
POWER_BTN23: C71.1, D71.C, J139.1, R120.1, S24.1
POWER_BTN24: C74.1, D74.C, J145.1, R125.1, S25.1
POWER_BTN25: C77.1, D77.C, J151.1, R130.1, S26.1
POWER_BTN26: C80.1, D80.C, J157.1, R135.1, S27.1
POWER_BTN27: C83.1, D83.C, J163.1, R140.1, S28.1
POWER_BTN28: C86.1, D86.C, J169.1, R145.1, S29.1
POWER_BTN29: C89.1, D89.C, J175.1, R150.1, S30.1
POWER_SENSE/CTRL: D2.C, D3.A, J3.3, R4.1, R5.2
POWER_SENSE/CTRL1: D5.A, D6.C, J12.3, R7.1, R8.2
POWER_SENSE/CTRL2: D8.A, D9.C, J18.3, R12.1, R13.2
POWER_SENSE/CTRL3: D11.A, D12.C, J24.3, R17.1, R18.2
POWER_SENSE/CTRL4: D14.A, D15.C, J30.3, R22.1, R23.2
POWER_SENSE/CTRL5: D17.A, D18.C, J36.3, R27.1, R28.2
POWER_SENSE/CTRL6: D20.A, D21.C, J42.3, R32.1, R33.2
POWER_SENSE/CTRL7: D23.A, D24.C, J48.3, R37.1, R38.2
POWER_SENSE/CTRL8: D26.A, D27.C, J54.3, R42.1, R43.2
POWER_SENSE/CTRL9: D29.A, D30.C, J60.3, R47.1, R48.2
POWER_SENSE/CTRL10: D32.A, D33.C, J66.3, R52.1, R53.2
POWER_SENSE/CTRL11: D35.A, D36.C, J72.3, R57.1, R58.2
POWER_SENSE/CTRL12: D38.A, D39.C, J78.3, R62.1, R63.2
POWER_SENSE/CTRL13: D41.A, D42.C, J84.3, R67.1, R68.2
POWER_SENSE/CTRL14: D44.A, D45.C, J90.3, R72.1, R73.2
POWER_SENSE/CTRL15: D47.A, D48.C, J96.3, R77.1, R78.2
POWER_SENSE/CTRL16: D50.A, D51.C, J102.3, R82.1, R83.2
POWER_SENSE/CTRL17: D53.A, D54.C, J108.3, R87.1, R88.2
POWER_SENSE/CTRL18: D56.A, D57.C, J114.3, R92.1, R93.2
POWER_SENSE/CTRL19: D59.A, D60.C, J120.3, R97.1, R98.2
POWER_SENSE/CTRL20: D62.A, D63.C, J126.3, R102.1, R103.2
POWER_SENSE/CTRL21: D65.A, D66.C, J132.3, R107.1, R108.2
POWER_SENSE/CTRL22: D68.A, D69.C, J138.3, R112.1, R113.2
POWER_SENSE/CTRL23: D71.A, D72.C, J144.3, R117.1, R118.2
POWER_SENSE/CTRL24: D74.A, D75.C, J150.3, R122.1, R123.2
POWER_SENSE/CTRL25: D77.A, D78.C, J156.3, R127.1, R128.2
POWER_SENSE/CTRL26: D80.A, D81.C, J162.3, R132.1, R133.2
POWER_SENSE/CTRL27: D83.A, D84.C, J168.3, R137.1, R138.2
POWER_SENSE/CTRL28: D86.A, D87.C, J174.3, R142.1, R143.2
POWER_SENSE/CTRL29: D89.A, D90.C, J180.3, R147.1, R148.2
VCC: C4.1, J2.2, J7.1, JP1.2, Q1.D2, R4.2
VCC1: C6.1, J9.1, J11.2, JP3.2, Q2.D2, R7.2
VCC2: C9.1, J16.1, J17.2, JP5.2, Q3.D2, R12.2
VCC3: C12.1, J22.1, J23.2, JP7.2, Q4.D2, R17.2
VCC4: C15.1, J28.1, J29.2, JP9.2, Q5.D2, R22.2
VCC5: C18.1, J34.1, J35.2, JP11.2, Q6.D2, R27.2
VCC6: C21.1, J40.1, J41.2, JP13.2, Q7.D2, R32.2
VCC7: C24.1, J46.1, J47.2, JP15.2, Q8.D2, R37.2
VCC8: C27.1, J52.1, J53.2, JP17.2, Q9.D2, R42.2
VCC9: C30.1, J58.1, J59.2, JP19.2, Q10.D2, R47.2
VCC10: C33.1, J64.1, J65.2, JP21.2, Q11.D2, R52.2
VCC11: C36.1, J70.1, J71.2, JP23.2, Q12.D2, R57.2
VCC12: C39.1, J76.1, J77.2, JP25.2, Q13.D2, R62.2
VCC13: C42.1, J82.1, J83.2, JP27.2, Q14.D2, R67.2
VCC14: C45.1, J88.1, J89.2, JP29.2, Q15.D2, R72.2
VCC15: C48.1, J94.1, J95.2, JP31.2, Q16.D2, R77.2
VCC16: C51.1, J100.1, J101.2, JP33.2, Q17.D2, R82.2
VCC17: C54.1, J106.1, J107.2, JP35.2, Q18.D2, R87.2
VCC18: C57.1, J112.1, J113.2, JP37.2, Q19.D2, R92.2
VCC19: C60.1, J118.1, J119.2, JP39.2, Q20.D2, R97.2
VCC20: C63.1, J124.1, J125.2, JP41.2, Q21.D2, R102.2
VCC21: C66.1, J130.1, J131.2, JP43.2, Q22.D2, R107.2
VCC22: C69.1, J136.1, J137.2, JP45.2, Q23.D2, R112.2
VCC23: C72.1, J142.1, J143.2, JP47.2, Q24.D2, R117.2
VCC24: C75.1, J148.1, J149.2, JP49.2, Q25.D2, R122.2
VCC25: C78.1, J154.1, J155.2, JP51.2, Q26.D2, R127.2
VCC26: C81.1, J160.1, J161.2, JP53.2, Q27.D2, R132.2
VCC27: C84.1, J166.1, J167.2, JP55.2, Q28.D2, R137.2
VCC28: C87.1, J172.1, J173.2, JP57.2, Q29.D2, R142.2
VCC29: C90.1, J178.1, J179.2, JP59.2, Q30.D2, R147.2
V_BATT: J8.2, J10.1, MEAS.1, MEAS.3
V_BATT1: J5.2, J6.1, MEAS1.1, MEAS1.3
V_BATT2: J14.2, J15.1, MEAS2.1, MEAS2.3
V_BATT3: J20.2, J21.1, MEAS3.1, MEAS3.3
V_BATT4: J26.2, J27.1, MEAS4.1, MEAS4.3
V_BATT5: J32.2, J33.1, MEAS5.1, MEAS5.3
V_BATT6: J38.2, J39.1, MEAS6.1, MEAS6.3
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

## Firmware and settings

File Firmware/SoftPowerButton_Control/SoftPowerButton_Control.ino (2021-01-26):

/*
  
  This example assume the Fast Off pin is connected.

  A simple tap of the power button will turn on the system.

  If the power button is not being pressed (accidental tap) the system will
  turn off after ~20ms.

  If the system turns on and sees the power button held for 0.5s, it will begin
  normal operation.

  During normal system operation, if user presses the power button for 2s, the system
  will shut down after an additional ~1500ms. So total turn off time is 3.5s
  
  Power on tap to turn off: 2453, 3694, 2932, 3219
  Software turnoff: 1386, 1135, 1440, 747, 1494, 1549
  Override hold time: 5599, 5052, 5596, 5055

  20-30nA at 70F
  Support charging, 120mV drop @ 180mA
*/

//int POWER_BUTTON = 7;
//int FAST_OFF = 8;

int POWER_BUTTON = 14;
int FAST_OFF = 32;
//int FAST_OFF = 13;//Temp testing

int STAT_LED = 13;

long powerPressedStartTime = 0;

int debounceDelay = 20;

//Uncomment the following line to turn on shutdown time measurements
//#define PRINT_TIMER_OUTPUT

void setup()
{
  Serial.begin(115200);
  Serial.println("Soft power switch testing");

  pinMode(POWER_BUTTON, INPUT_PULLUP);

  //User has pressed the power button to turn on the system
  //Was it an accidental bump or do they really want to turn on?
  //Let's make sure they continue to press for two seconds
  Serial.print("Initial power on check.");
  powerPressedStartTime = millis();
  while (digitalRead(POWER_BUTTON) == LOW)
  {
    //Wait for user to stop pressing button.
    //What if user has left something heavy pressing the power button?
    //The soft power switch will automatically turn off the system! Handy.
    delay(100);

    if (millis() - powerPressedStartTime > 500)
      break;
    Serial.print(".");
  }
  Serial.println();

  if (millis() - powerPressedStartTime < 500)
  {
    Serial.println("Power button tap. Returning to off state. Powering down.");
    powerDown();
  }

  Serial.println("User wants to turn system on!");
  powerPressedStartTime = 0; //Reset var to return to normal 'on' state

  //Here we display something to user indicating system is on and running
  //For example an external display or LED turns on
  pinMode(STAT_LED, OUTPUT);
  digitalWrite(STAT_LED, HIGH);

  Serial.println("Press 'r' to enter infinite loop to test power-down override");
  Serial.println("Press 'z' to do a soft powerdown");
  Serial.println("Press and hold power button for 2.5 to do a soft powerdown");
}

void loop()
{
  if (Serial.available())
  {
    byte incoming = Serial.read();

    if (incoming == 'z')
    {
      Serial.println("Powering down");
      powerDown();
    }
    else if (incoming == 'r')
    {
      Serial.println("System locked. Now hold power button to force power down without using software.");

      //Here we wait for user press button so we can time it
      while (digitalRead(POWER_BUTTON) == HIGH) delay(1);

      powerPressedStartTime = millis();
      Serial.print("Doing nothing, waiting for power override to kick in");
      while (1)
      {
#ifdef PRINT_TIMER_OUTPUT
        Serial.println(millis() - powerPressedStartTime);
#endif
        delay(1);

        if(digitalRead(POWER_BUTTON) == HIGH) break;
      }
      Serial.println("User released button before forced powered could complete. Try again, but hold power button for 10s.");
    }
  }

  if (digitalRead(POWER_BUTTON) == LOW && powerPressedStartTime == 0)
  {
    //Debounce check
    delay(debounceDelay);
    if (digitalRead(POWER_BUTTON) == LOW)
    {
      Serial.println("User is pressing power button. Start timer.");
      powerPressedStartTime = millis();
    }
  }
  else if (digitalRead(POWER_BUTTON) == LOW && powerPressedStartTime > 0)
  {
    //Debounce check
    delay(debounceDelay);
    if (digitalRead(POWER_BUTTON) == LOW)
    {
      if ((millis() - powerPressedStartTime) > 2000)
      {
        Serial.println("Time to power down!");
        powerDown();
      }
    }
  }
  else if (digitalRead(POWER_BUTTON) == HIGH && powerPressedStartTime > 0)
  {
    //Debounce check
    delay(debounceDelay);
    if (digitalRead(POWER_BUTTON) == HIGH)
    {
      Serial.print("Power button released after ms: ");
      Serial.println(millis() - powerPressedStartTime);
    }
    powerPressedStartTime = 0; //Reset var to return to normal 'on' state
  }
}

void powerDown()
{
  //Indicate to user we are shutting down
  digitalWrite(STAT_LED, LOW);

  pinMode(POWER_BUTTON, OUTPUT);
  digitalWrite(POWER_BUTTON, LOW);

  pinMode(FAST_OFF, OUTPUT);
  digitalWrite(FAST_OFF, LOW);

  powerPressedStartTime = millis();
  Serial.print("Pulling power line low");
  while (1)
  {
#ifdef PRINT_TIMER_OUTPUT
    Serial.println(millis() - powerPressedStartTime);
#endif
    delay(1);
  }
}

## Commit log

2021-01-26 x02: Add fast off. Add zener protection. Increase V rating of cap. Increase cap size.
    [SparkFun Soft Power Switch-Panel.brd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]
2021-01-26 Schematic compress
    [SparkFun Soft Power Switch.sch]
2021-02-08 Replace MOSFET with SIL2308-TP
    [SparkFun Soft Power Switch.brd, SparkFun Soft Power Switch.sch]
2021-02-08 Replace MOSFET on panel.
    [SparkFun Soft Power Switch-Panel.GBL, SparkFun Soft Power Switch-Panel.GBO, SparkFun Soft Power Switch-Panel.GBP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]
2021-02-16 Add prod ID to power LED.
    [SparkFun Soft Power Switch.brd, SparkFun Soft Power Switch.sch]
2021-04-19 Add 12VGS max note
    [SparkFun Soft Power Switch.sch]

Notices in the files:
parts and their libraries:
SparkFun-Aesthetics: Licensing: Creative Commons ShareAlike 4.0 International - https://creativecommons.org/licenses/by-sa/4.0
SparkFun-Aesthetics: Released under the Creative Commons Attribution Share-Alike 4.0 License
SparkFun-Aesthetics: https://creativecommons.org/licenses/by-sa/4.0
